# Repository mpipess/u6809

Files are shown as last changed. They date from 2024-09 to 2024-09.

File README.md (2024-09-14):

# u6809

## Project Description

This project allowed me to follow along with Ben Eater's 6502 series while still doing original work.
Architecturally, both systems are similar in scope, but use different components.

I originally intended for this to be a breadboard computer forever, but the temptation to tweak the design was too strong.
Solidifying it as a PCB allowed me to feel "done" with it.

## Primary Components

1. Motorola MC6809E (microprocessor)
2. Motorola MC6821 (peripheral interface adapter)
3. Motorola MC6840 (programmable timer module)
4. Motorola MC6850 (asynchronous communications interface adapter)
5. Alliance AS6C6264 (8 KB SRAM)
6. Winbond W27C512 (64 KB EEPROM)

## Project Status

I froze the design sometime in early Spring 2024 in order to focus on other things. It works well enough to blink some lights, but I haven't tested everything, especially the ACIA.

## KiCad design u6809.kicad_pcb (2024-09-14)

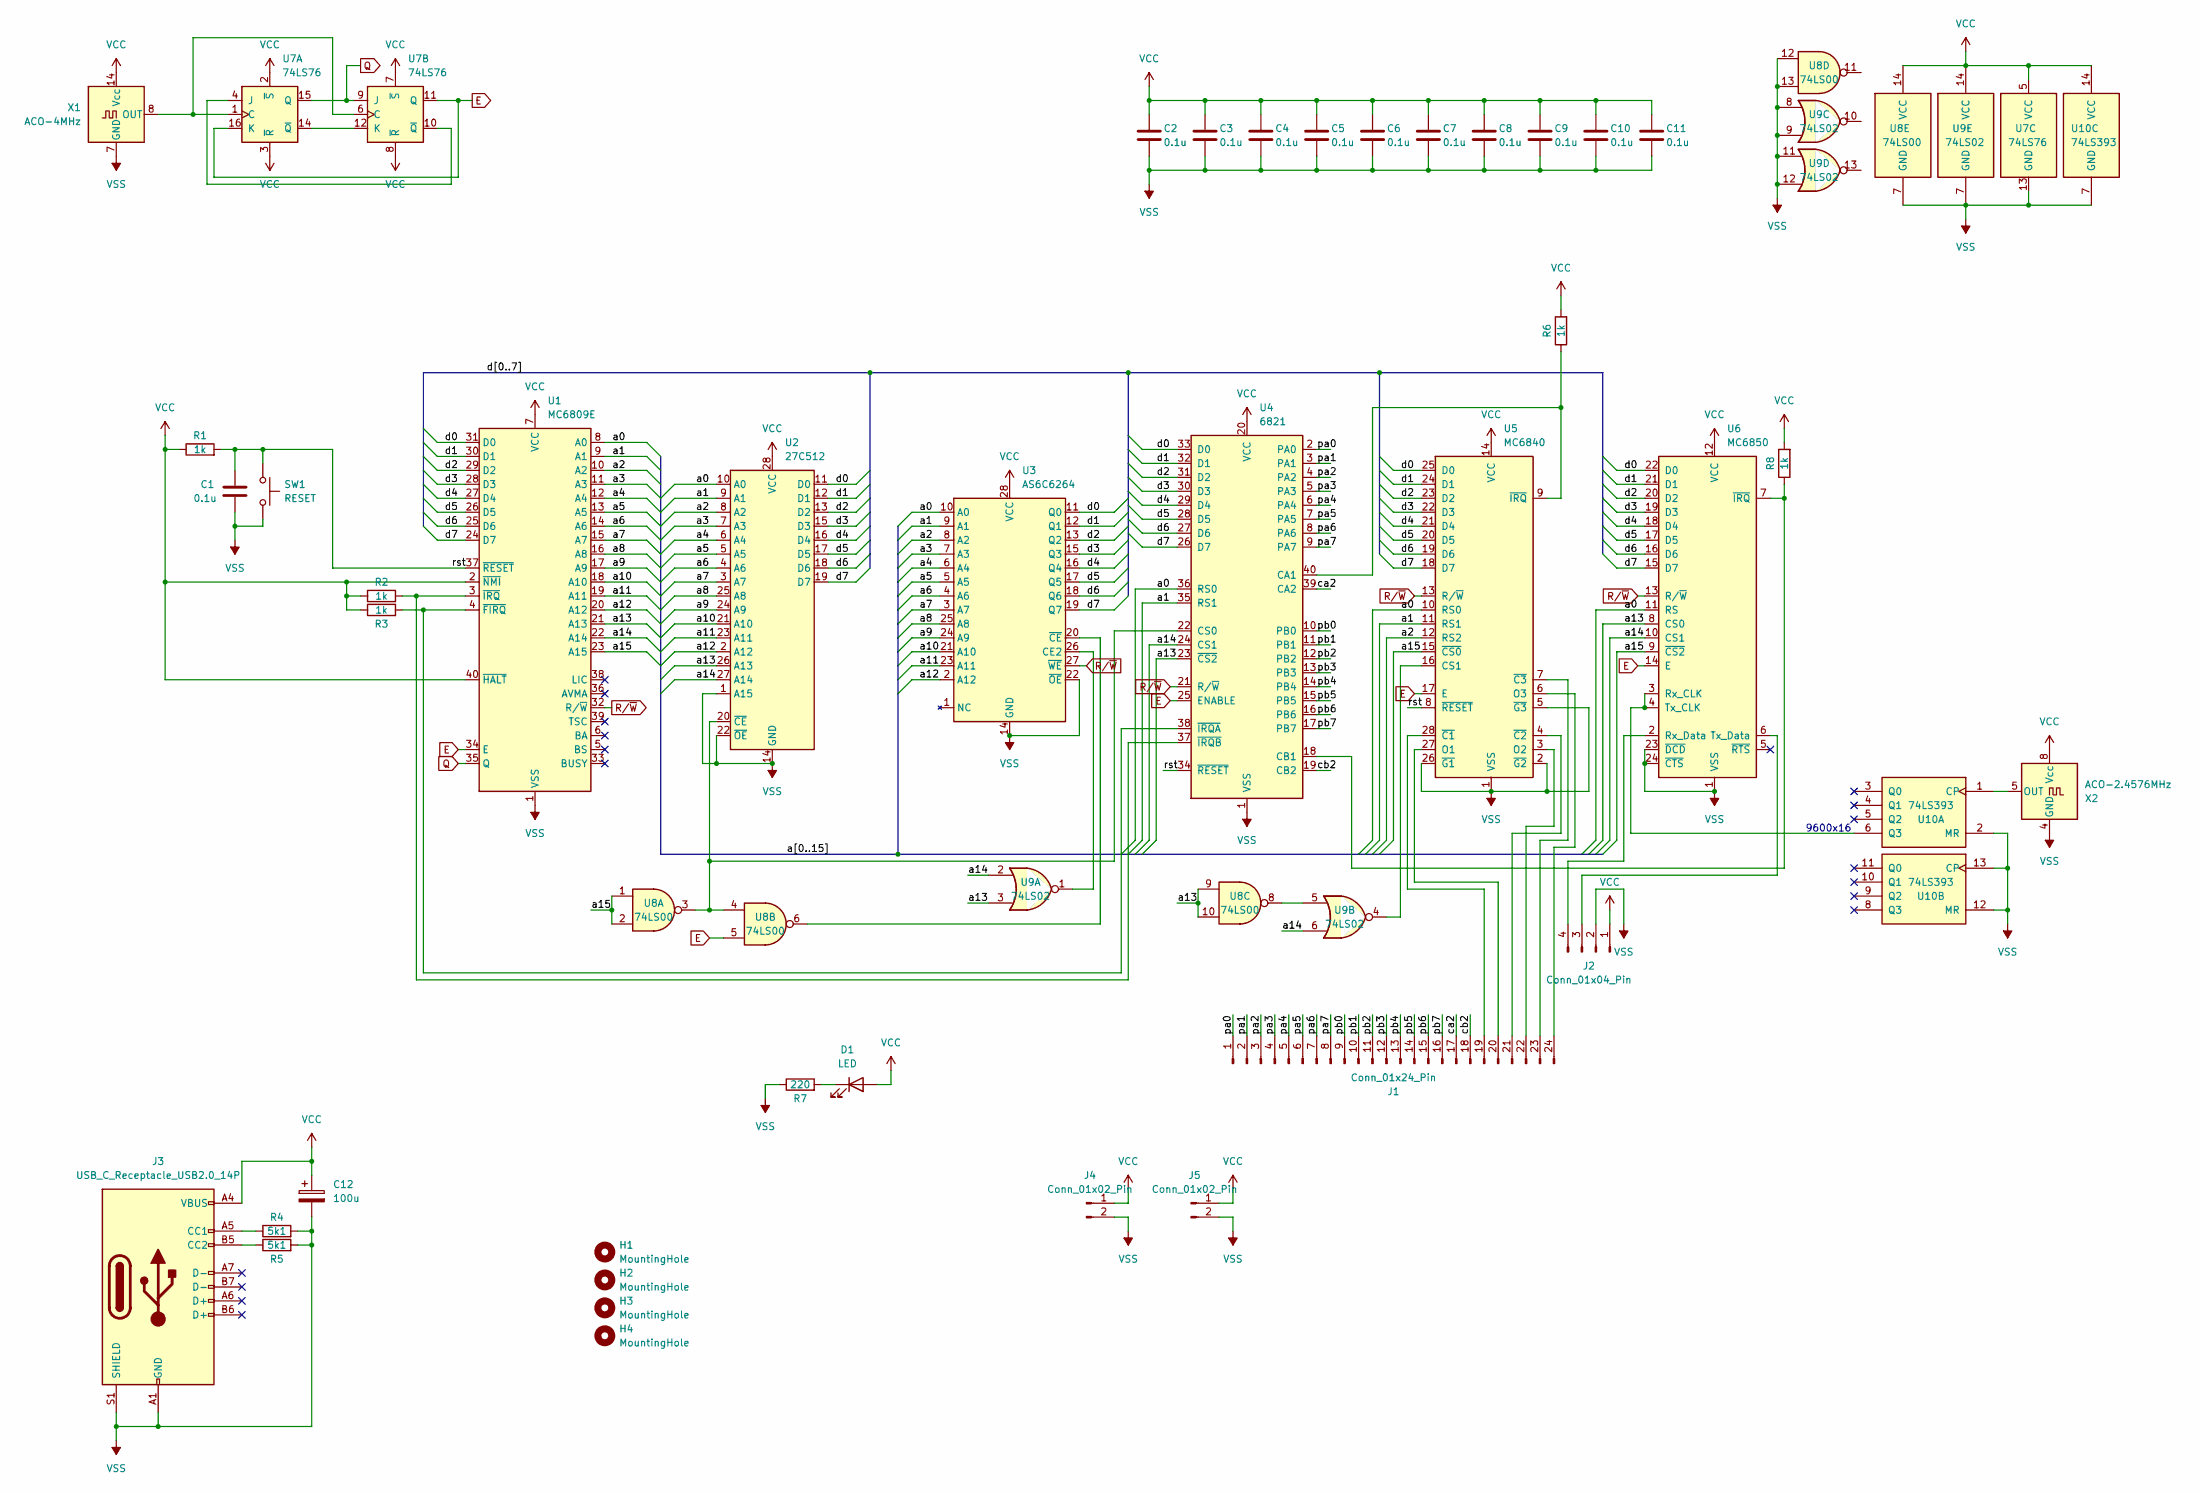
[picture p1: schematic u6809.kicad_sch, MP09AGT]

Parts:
C1, C2, C3, C4, C5, C6, C7, C8, C9, C10, C11: 0.1u; C_Disc_D4.3mm_W1.9mm_P5.00mm
C12: 100u; CP_Radial_D10.0mm_P5.00mm
D1: LED; LED_D3.0mm
H1, H2, H3, H4: MountingHole; MountingHole_3.2mm_M3
J1: Conn_01x24_Pin; PinHeader_1x24_P2.54mm_Vertical
J2: Conn_01x04_Pin; PinHeader_1x04_P2.54mm_Vertical
J3: USB_C_Receptacle_USB2.0_14P; USB_C_Receptacle_HRO_TYPE-C-31-M-12
J4, J5: Conn_01x02_Pin; PinHeader_1x02_P2.54mm_Vertical
R1, R2, R3, R6, R8: 1k; R_Axial_DIN0207_L6.3mm_D2.5mm_P7.62mm_Horizontal
R4, R5: 5k1; R_Axial_DIN0207_L6.3mm_D2.5mm_P7.62mm_Horizontal
R7: 220; R_Axial_DIN0207_L6.3mm_D2.5mm_P7.62mm_Horizontal
SW1: RESET; SW_PUSH_6mm
U1: MC6809E; DIP-40_W15.24mm_Socket
U2: 27C512; DIP-28_W15.24mm_Socket
U3: AS6C6264; DIP-28_W15.24mm_Socket
U4: 6821; DIP-40_W15.24mm_Socket
U5: MC6840; DIP-28_W15.24mm_Socket
U6: MC6850; DIP-24_W15.24mm_Socket
U7: 74LS76; DIP-16_W7.62mm_Socket
U8: 74LS00; DIP-14_W7.62mm_Socket
U9: 74LS02; DIP-14_W7.62mm_Socket
U10: 74LS393; DIP-14_W7.62mm_Socket
X1: ACO-4MHz; Oscillator_DIP-14
X2: ACO-2.4576MHz; Oscillator_DIP-8

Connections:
/a0: U1.8 (A0), U2.10 (A0), U3.10 (A0), U4.36 (RS0), U5.10 (RS0), U6.11 (RS)
/a1: U1.9 (A1), U2.9 (A1), U3.9 (A1), U4.35 (RS1), U5.11 (RS1)
/a2: U1.10 (A2), U2.8 (A2), U3.8 (A2), U5.12 (RS2)
/a3: U1.11 (A3), U2.7 (A3), U3.7 (A3)
/a4: U1.12 (A4), U2.6 (A4), U3.6 (A4)
/a5: U1.13 (A5), U2.5 (A5), U3.5 (A5)
/a6: U1.14 (A6), U2.4 (A6), U3.4 (A6)
/a7: U1.15 (A7), U2.3 (A7), U3.3 (A7)
/a8: U1.16 (A8), U2.25 (A8), U3.25 (A8)
/a9: U1.17 (A9), U2.24 (A9), U3.24 (A9)
/a10: U1.18 (A10), U2.21 (A10), U3.21 (A10)
/a11: U1.19 (A11), U2.23 (A11), U3.23 (A11)
/a12: U1.20 (A12), U2.2 (A12), U3.2 (A12)
/a13: U1.21 (A13), U2.26 (A13), U4.23 (~CS2), U6.8 (CS0), U8.9, U8.10, U9.3
/a14: U1.22 (A14), U2.27 (A14), U4.24 (CS1), U6.10 (CS1), U9.2, U9.6
/a15: U1.23 (A15), U5.15 (~CS0), U6.9 (~CS2), U8.1, U8.2
/ca2: J1.17, U4.39 (CA2)
/cb2: J1.18, U4.19 (CB2)
/d0: U1.31 (D0), U2.11 (D0), U3.11 (Q0), U4.33 (D0), U5.25 (D0), U6.22 (D0)
/d1: U1.30 (D1), U2.12 (D1), U3.12 (Q1), U4.32 (D1), U5.24 (D1), U6.21 (D1)
/d2: U1.29 (D2), U2.13 (D2), U3.13 (Q2), U4.31 (D2), U5.23 (D2), U6.20 (D2)
/d3: U1.28 (D3), U2.15 (D3), U3.15 (Q3), U4.30 (D3), U5.22 (D3), U6.19 (D3)
/d4: U1.27 (D4), U2.16 (D4), U3.16 (Q4), U4.29 (D4), U5.21 (D4), U6.18 (D4)
/d5: U1.26 (D5), U2.17 (D5), U3.17 (Q5), U4.28 (D5), U5.20 (D5), U6.17 (D5)
/d6: U1.25 (D6), U2.18 (D6), U3.18 (Q6), U4.27 (D6), U5.19 (D6), U6.16 (D6)
/d7: U1.24 (D7), U2.19 (D7), U3.19 (Q7), U4.26 (D7), U5.18 (D7), U6.15 (D7)
/pa0: J1.1, U4.2 (PA0)
/pa1: J1.2, U4.3 (PA1)
/pa2: J1.3, U4.4 (PA2)
/pa3: J1.4, U4.5 (PA3)
/pa4: J1.5, U4.6 (PA4)
/pa5: J1.6, U4.7 (PA5)
/pa6: J1.7, U4.8 (PA6)
/pa7: J1.8, U4.9 (PA7)
/pb0: J1.9, U4.10 (PB0)
/pb1: J1.10, U4.11 (PB1)
/pb2: J1.11, U4.12 (PB2)
/pb3: J1.12, U4.13 (PB3)
/pb4: J1.13, U4.14 (PB4)
/pb5: J1.14, U4.15 (PB5)
/pb6: J1.15, U4.16 (PB6)
/pb7: J1.16, U4.17 (PB7)
/rst: C1.2, R1.2, SW1.1, U1.37 (~RESET), U4.34 (~RESET), U5.8 (~RESET)
E: U1.34 (E), U4.25 (ENABLE), U5.17 (E), U6.14 (E), U7.11 (Q), U7.16 (K), U8.5
unnamed: D1.1 (K), R7.2
unnamed: J1.19, U5.28 (~C1)
unnamed: J1.20, U5.27 (O1)
unnamed: J1.21, U5.4 (~C2)
unnamed: J1.22, U5.3 (O2)
unnamed: J1.23, U5.7 (~C3)
unnamed: J1.24, U5.6 (O3)
unnamed: J2.3, U6.6 (Tx_Data)
unnamed: J2.4, U6.2 (Rx_Data)
unnamed: J3.A5 (CC1), R4.1
unnamed: J3.B5 (CC2), R5.1
unnamed: R3.2, U1.4 (~FIRQ), U4.38 (~IRQA)
unnamed: R2.2, U1.3 (~IRQ), U4.37 (~IRQB)
unnamed: U2.20 (~CE), U4.22 (CS0), U8.3, U8.4
unnamed: U3.26 (CE2), U9.1
unnamed: U3.20 (~CE), U8.6
unnamed: R6.1, U4.40 (CA1), U5.9 (~IRQ)
unnamed: R8.1, U4.18 (CB1), U6.7 (~IRQ)
unnamed: U5.16 (CS1), U9.4
unnamed: U7.1 (C), U7.6 (C), X1.8 (OUT)
unnamed: U7.4 (J), U7.10 (~Q)
unnamed: U7.12 (K), U7.14 (~Q)
unnamed: U8.8, U9.5
unnamed: U10.1 (CP), X2.5 (OUT)
unnamed: U6.3 (Rx_CLK), U6.4 (Tx_CLK), U10.6 (Q3)
Q: U1.35 (Q), U7.9 (J), U7.15 (Q)
R/~W: U1.32 (R/~W), U3.27 (~WE), U4.21 (R/~W), U5.13 (R/~W), U6.13 (R/~W)
VCC: C2.1, C3.1, C4.1, C5.1, C6.1, C7.1, C8.1, C9.1, C10.1, C11.1, C12.1, D1.2 (A), J2.1, J3.A4 (VBUS), J3.A9 (VBUS), J3.B4 (VBUS), J3.B9 (VBUS), J4.1, J5.1, R1.1, R2.1, R3.1, R6.2, R8.2, U1.2 (~NMI), U1.7 (VCC), U1.40 (~HALT), U2.28 (VCC), U3.28 (VCC), U4.20 (VCC), U5.14 (VCC), U6.12 (VCC), U7.2 (~S), U7.3 (~R), U7.5 (VCC), U7.7 (~S), U7.8 (~R), U8.14 (VCC), U9.14 (VCC), U10.14 (VCC), X1.14 (Vcc), X2.8 (Vcc)
VSS: C1.1, C2.2, C3.2, C4.2, C5.2, C6.2, C7.2, C8.2, C9.2, C10.2, C11.2, C12.2, J2.2, J3.A1 (GND), J3.A12 (GND), J3.B1 (GND), J3.B12 (GND), J3.S1 (SHIELD), J4.2, J5.2, R4.2, R5.2, R7.1, SW1.2, U1.1 (VSS), U2.1 (A15), U2.14 (GND), U2.22 (~OE), U3.14 (GND), U3.22 (~OE), U4.1 (VSS), U5.1 (VSS), U5.2 (~G2), U5.5 (~G3), U5.26 (~G1), U6.1 (VSS), U6.23 (~DCD), U6.24 (~CTS), U7.13 (GND), U8.7 (GND), U8.12, U8.13, U9.7 (GND), U9.8, U9.9, U9.11, U9.12, U10.2 (MR), U10.7 (GND), U10.12 (MR), U10.13 (CP), X1.7 (GND), X2.4 (GND)

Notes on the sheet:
9600x16

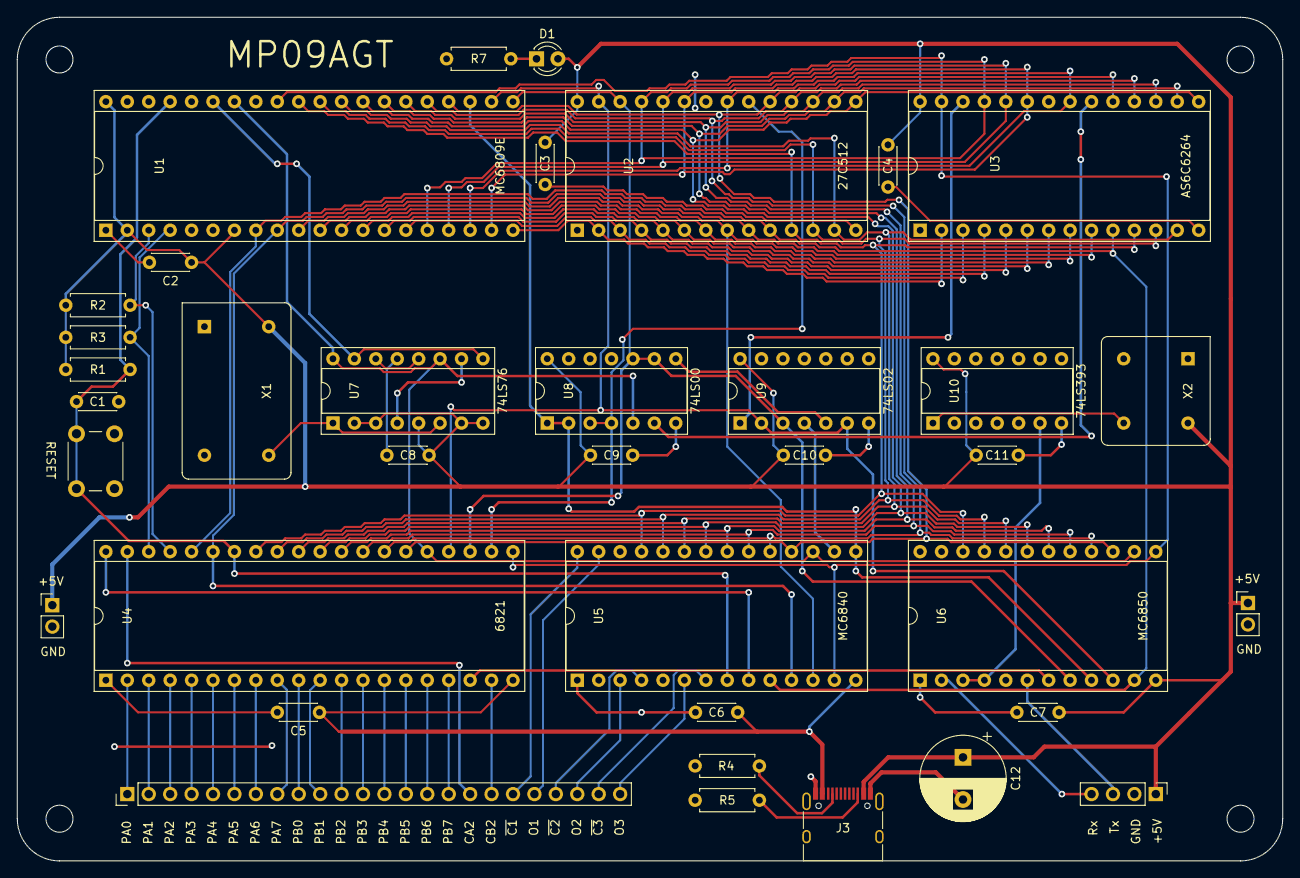
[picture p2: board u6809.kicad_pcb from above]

Board: 2 copper layers, 150.0 x 100.0 mm, 41 parts (0 on the bottom side), 73 nets.
